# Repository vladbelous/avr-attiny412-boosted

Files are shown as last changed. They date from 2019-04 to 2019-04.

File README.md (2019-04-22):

# ATtiny412-based board with on-board boost regulator

Small ATtiny412 board powered by a boost regulator (MCP1640, or pin-compatible MCP16251, TPS6107x; check FB voltage).

Two powering options:
* Li-Ion battery: place voltage-supervisor MIC809 (U2) and R2 pull-down resistor -- this will protect the battery from discharging below 2.93V.
* Single/double AA battery: can skip MIC809 and place R1 instead -- this will put boost regulator in always-on mode.

Optional:
* Power distribution switch IC (MIC9409x) for the common use case of driving a LED strip (WS2812B, APA106, etc), or other, possibly capacitative, loads.
* Pull-up resistors for I2C on botton side (on pins PA1 = SDA, and PA2 = SCL).

Designed with KiCad 5 (www.kicad-pcb.org).

## Schematic:
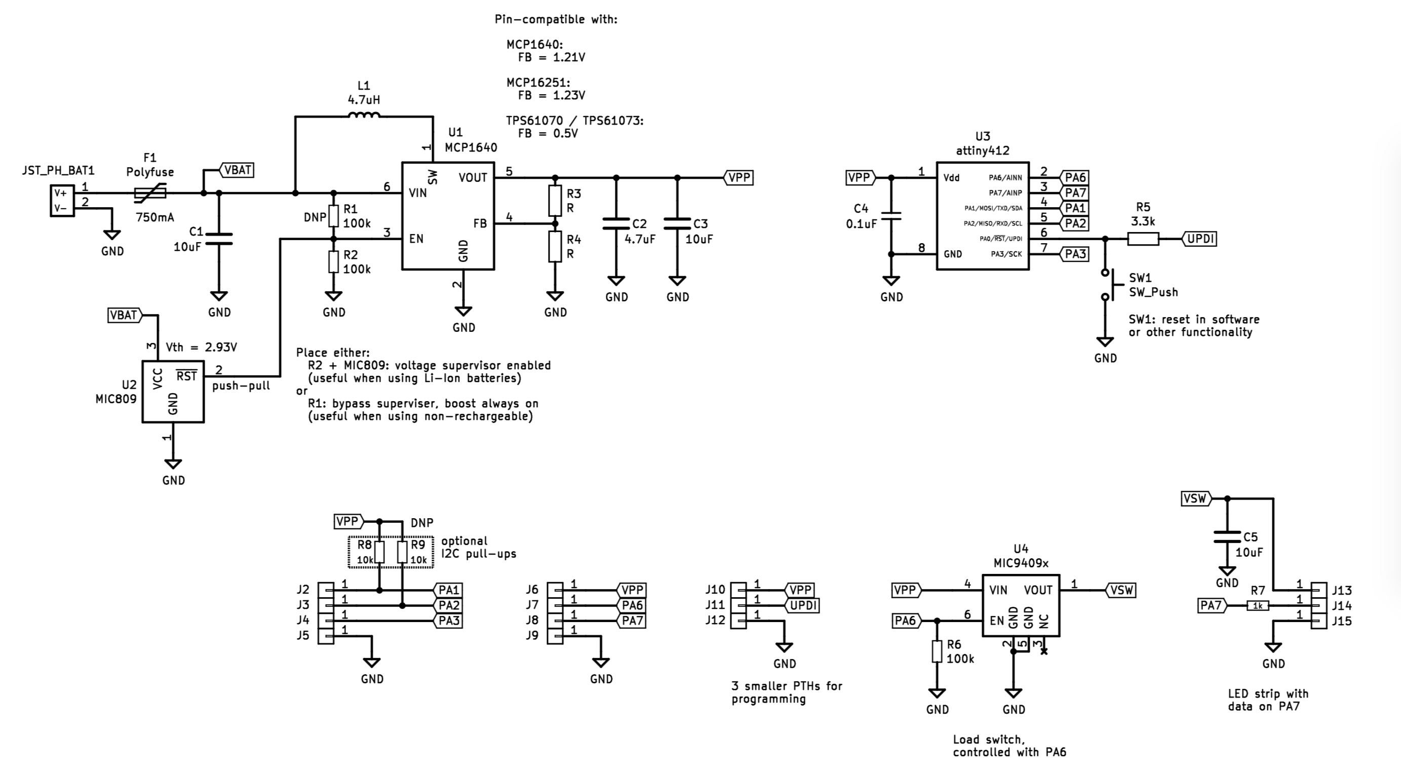
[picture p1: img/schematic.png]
schematic


## Layout:
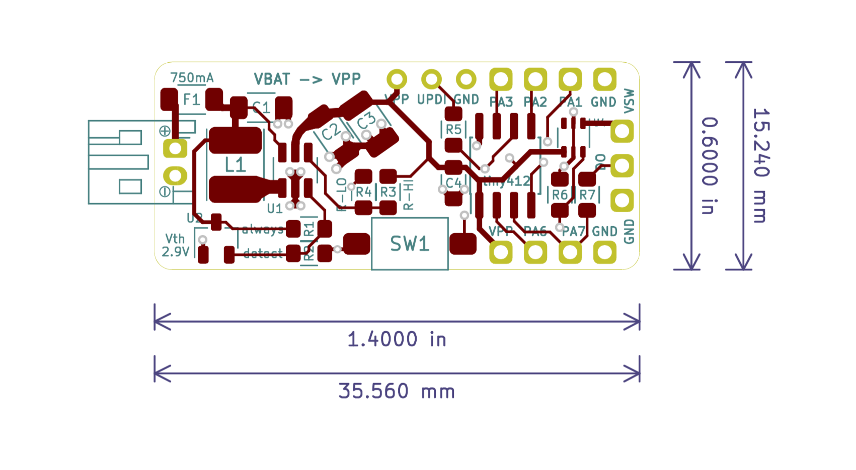
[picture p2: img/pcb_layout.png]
layout


## Assembled:
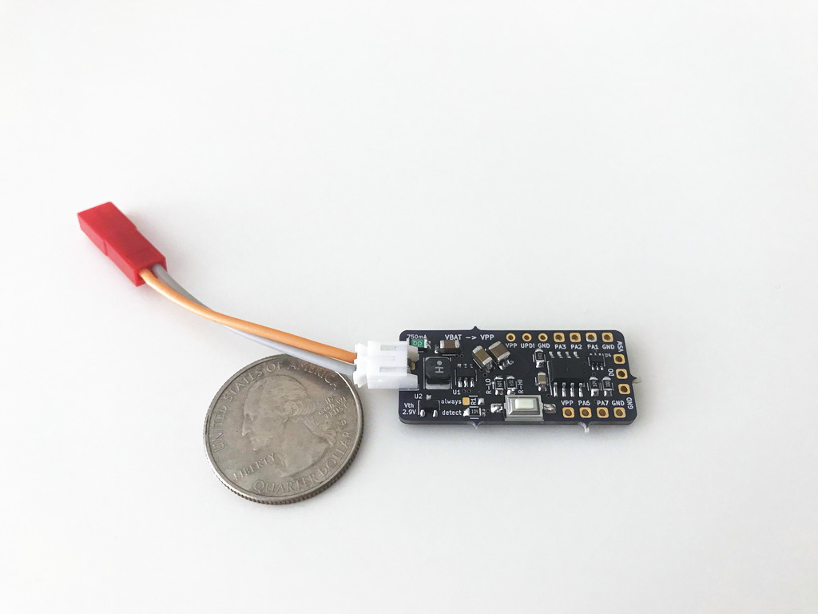
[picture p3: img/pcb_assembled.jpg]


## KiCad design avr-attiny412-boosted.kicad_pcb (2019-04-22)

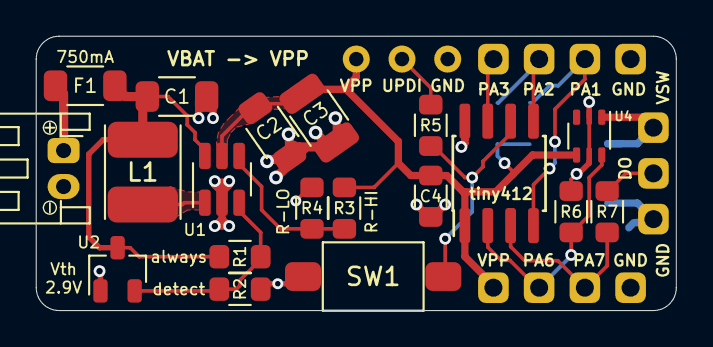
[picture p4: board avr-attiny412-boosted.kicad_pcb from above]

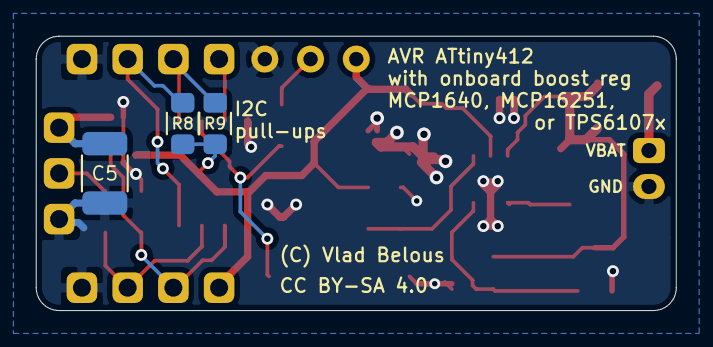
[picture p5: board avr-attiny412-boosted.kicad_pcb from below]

Board: 2 copper layers, 35.6 x 15.2 mm, 36 parts (3 on the bottom side), 16 nets.

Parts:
C1: 10uF; 1206_HS
C2: 4.7uF; 1206_HS
C3, C5: 10uF; 1210_HS
C4: 0.1uF; 0805_HS
F1: Polyfuse; 1206_HS
J2, J3, J4, J5, J6, J7, J8, J9, J13, J14, J15: Conn_01x01; Pin_Header_Straight_1x01_Pitch2.54mm
J10, J11, J12: Conn_01x01; Conn_1-wire
JST_PH_BAT1: JST_PH_BAT; JST_PH_S2B-PH-K_02x2.00mm_Angled_WiderHole
L1: 4.7uH; L_Taiyo-Yuden_NR-S-40xx_HS
R1, R2, R6: 100k; 0805_HS
R3, R4: R; 0805_HS
R5: 3.3k; 0805_HS
R7: 1k; 0805_HS
R8, R9: 10k; 0805_HS
SW1: SW_Push; SW_SPST_PUSH_6mm_3mm
U1: MCP1640; SOT-23-6_HS
U2: MIC809; SOT-23_HS
U3: attiny412; SOIC-8_3.9x4.9mm_Pitch1.27mm_HS
U4: MIC9409x; SOT-363_SC-70-6_HS

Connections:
GND: C1.2, C2.2, C3.2, C4.2, C5.2, J5.1, J9.1, J12.1, J15.1, JST_PH_BAT1.2, R2.2, R4.2, R6.2, SW1.2, U1.2, U2.1, U3.8, U4.2, U4.5
unnamed: F1.2, JST_PH_BAT1.1
unnamed: J14.1, R7.1
unnamed: L1.2, U1.1
unnamed: R1.2, R2.1, U1.3, U2.2
unnamed: R3.2, R4.1, U1.4
unnamed: R5.2, SW1.1, U3.6
PA1: J2.1, R8.2, U3.4
PA2: J3.1, R9.2, U3.5
PA3: J4.1, U3.7
PA6: J7.1, R6.1, U3.2, U4.6
PA7: J8.1, R7.2, U3.3
UPDI: J11.1, R5.1
VBAT: C1.1, F1.1, L1.1, R1.1, U1.6, U2.3
VPP: C2.1, C3.1, C4.1, J6.1, J10.1, R3.1, R8.1, R9.1, U1.5, U3.1, U4.4
VSW: C5.1, J13.1, U4.1

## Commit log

2018-12-03 Initial commit. Schematic for MCP16251T-based boost module.
    [mcp16251-boost-with-latch.kicad_pcb, mcp16251-boost-with-latch.sch]
2018-12-03 Added license.
    [mcp16251-boost-with-latch.sch]
2018-12-03 Battery input SPDT switch
    [mcp16251-boost-with-latch.sch]
2018-12-03 Create and assign footprints.
    [mcp16251-boost-with-latch.sch]
2018-12-03 Set design rules
    [mcp16251-boost-with-latch.kicad_pcb]
2018-12-03 MCP16251 layout according to datasheet recommendation
    [mcp16251-boost-with-latch.kicad_pcb]
2018-12-03 Further layout
    [mcp16251-boost-with-latch.kicad_pcb]
2018-12-03 Try alternative (more square-ish) layout
    [mcp16251-boost-with-latch.kicad_pcb, mcp16251-boost-with-latch.sch]
2018-12-03 Completed alternative layout. Size 1.3in x 0.9in
    [mcp16251-boost-with-latch.kicad_pcb]
2018-12-05 Silkscreen texts
    [mcp16251-boost-with-latch.kicad_pcb]
2019-04-04 Re-use project
    [avr-attiny412-boosted.sch, mcp16251-boost-with-latch.kicad_pcb, mcp16251-boost-with-latch.sch]
2019-04-04 Partial schematic
    [avr-attiny412-boosted.sch]
2019-04-07 Add load switch symbol, and complete schematic (pending validation)
    [avr-attiny412-boosted.sch]
2019-04-07 Fix LED load capacitor
    [avr-attiny412-boosted.sch]
2019-04-07 Improve footprints (inductor, JST PH, SC-70-6), add JST BAT schematic symbol
    [avr-attiny412-boosted.sch]
2019-04-07 Footprints, minor fixes, footprint assignment, netlist
    [avr-attiny412-boosted.sch]
2019-04-07 Initial PCB arrangement
    [avr-attiny412-boosted.kicad_pcb]
2019-04-07 Schematic picture
2019-04-07 Approximate placement, no routing
    [avr-attiny412-boosted.kicad_pcb]
2019-04-08 Final layout and silkcreen. Add layout picture
    [avr-attiny412-boosted.kicad_pcb]
2019-04-08 Adjust prog pin locations
    [avr-attiny412-boosted.kicad_pcb]
2019-04-22 Clearance update
    [avr-attiny412-boosted.kicad_pcb]

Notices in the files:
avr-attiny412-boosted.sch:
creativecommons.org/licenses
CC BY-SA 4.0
